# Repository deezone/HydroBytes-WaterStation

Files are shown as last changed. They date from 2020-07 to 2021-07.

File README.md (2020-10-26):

# HydroBytes-WaterManagement
A collection of systems using micro controllers to manage water in an automated garden.

## Introduction

The "garden" is simply a backyard patio in Brooklyn, New York. Typically there are only two seasons - cold and hot in New York City. By automating an urban garden ideally the space will thrive with minimum supervision. The amount of effort to automate is besides the point, everyone needs their vices.

- **Water Management**
- **[Base Station](https://github.com/deezone/HydroBytes-BaseStation)**

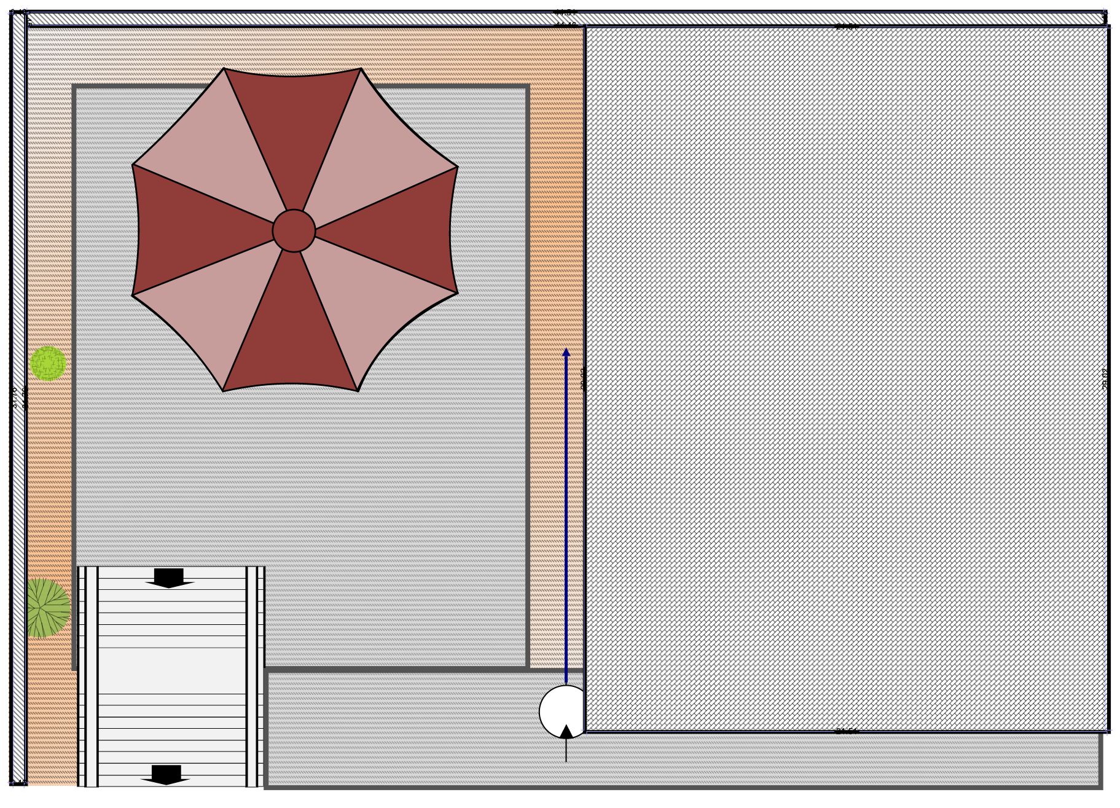
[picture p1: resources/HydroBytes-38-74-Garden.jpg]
Garden Layout


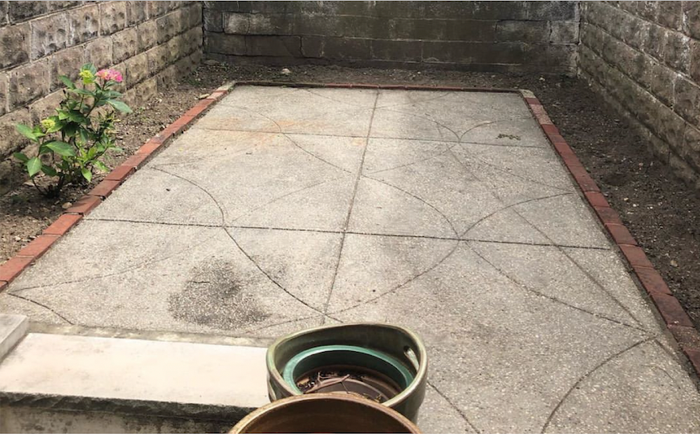
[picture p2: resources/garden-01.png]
Garden


### YouTube Channel

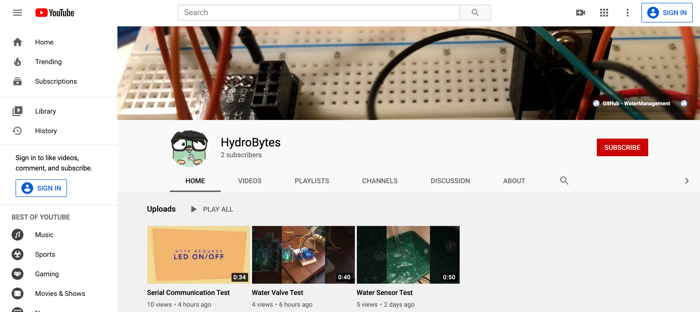
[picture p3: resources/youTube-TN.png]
YouTube Channel (https://www.youtube.com/channel/UC00A_lEJD2Hcy9bw6UuoUBA "All of the HydroBytes videos")


## The Water Management System

This repo is for the Water Management systems of the project. It's responsibilities are:
- adding water to a water reservoir (rain barrel)
- monitor the water level in the water reservoir
- pumping water to the garden. Sensor systems in the garden will coordinate with the Water Management system based on the conditions
- provide access and control of the subsystems through REST API requests
- send status and related readings to the Central System

### Release Notes
Resources and thoughts on each release. Development details as well as links to help explain choices made in how the system was built.

- [v0.2.1 - 24 October 2020](https://github.com/deezone/HydroBytes-waterManagement/blob/master/resources/releases/v00-02-01.md)
Adds duration  GET /water responses to indicate the amount of time since the water pump state has been toggled.
- [v0.2.0 - 18 October 2020](https://github.com/deezone/HydroBytes-waterManagement/blob/master/resources/releases/v00-02-00.md)
Water irrigation support. A request to irrigate the garden includes monitoring the current water level available.
- [v0.1.1 - 27 September 2020](https://github.com/deezone/HydroBytes-waterManagement/blob/master/resources/releases/v00-01-01.md)
Addition of YouTube channel as well as general release notes clean up to include images and videos to help document the project.
- [v0.1.0 - 30 August 2020](https://github.com/deezone/HydroBytes-waterManagement/blob/master/resources/releases/v00-01-00.md)
Water level detection on water barrel.
- [v0.0.3 - 15 August 2020](https://github.com/deezone/HydroBytes-waterManagement/blob/master/resources/releases/v00-00-03.md)
Working proof of concept. LED control and monitoring of state with http requests.
- [v0.0.2 - 14 August 2020](https://github.com/deezone/HydroBytes-waterManagement/blob/master/resources/releases/v00-00-02.md)
Adds functional two way serial communication between Ardunio Uno and ESP8266 ESP-01 as a part of a GET /status 200 response.
- [v0.0.1 - 25 July 2020](https://github.com/deezone/HydroBytes-waterManagement/blob/master/resources/releases/v00-00-01.md)
Functional solution to two controllers - Arduino Uno and ESP8266 ESP-01 communicating through a serial connection. The ESP provides a WiFi access point and the Uno works with all of the sensors.

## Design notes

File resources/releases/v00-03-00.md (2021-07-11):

# Release v0.4.0
16 June 2021

### Features

- Switch to the NodeESP (ESP-12f)

- Add DS3231 hardware for real time clock functionality
- Add clock values to irrigation duration calculations

### Bug Fixes

- 

### Refactors

- 

### Learnings

- 

**References**:

- [Library: DS3231](http://www.rinkydinkelectronics.com/library.php?id=73)
The DS3231 is a low-cost, extremely accurate I2C realtime clock (RTC) with an integrated temperature-compensated crystal oscillator (TCXO) and crystal. The device incorporates a battery input, and maintains accurate timekeeping when main power to the device is interrupted. The integration of the crystal resonator enhances the long-term accuracy of the device as well as reduces the piece-part count in a manufacturing line.
- [Installing Additional Arduino Libraries - Importing a .zip Library](https://www.arduino.cc/en/guide/libraries#toc4)
- [Arduino and DS3231 Real Time Clock Tutorial](https://howtomechatronics.com/tutorials/arduino/arduino-ds3231-real-time-clock-tutorial/)
Learn how to use the DS3231 Real Time Clock Module
- [8 tips to use the String class efficiently](https://cpp4arduino.com/2018/11/21/eight-tips-to-use-the-string-class-efficiently.html)
The String class provides a convenient means to bring a Flash string into the RAM temporarily. Avoiding heap allocation is not always possible. Many Arduino cores (most notably the ones for ESP8266 and ESP32) put a very low limit on the stack size, so it’s not possible to put large strings there. In this case, using the String class makes perfect sense. Some libraries (for example ESP8266WebServer) force the use the String class.

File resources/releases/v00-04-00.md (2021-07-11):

# Release v0.4.0
16 June 2021

### Features

- Switch to the NodeESP (ESP-12f)

- Add DS3231 hardware for real time clock functionality
- Add clock values to irrigation duration calculations

### Bug Fixes

- 

### Refactors

- 

### Learnings

- 

**References**:

- [Library: DS3231](http://www.rinkydinkelectronics.com/library.php?id=73)
The DS3231 is a low-cost, extremely accurate I2C realtime clock (RTC) with an integrated temperature-compensated crystal oscillator (TCXO) and crystal. The device incorporates a battery input, and maintains accurate timekeeping when main power to the device is interrupted. The integration of the crystal resonator enhances the long-term accuracy of the device as well as reduces the piece-part count in a manufacturing line.
- [Installing Additional Arduino Libraries - Importing a .zip Library](https://www.arduino.cc/en/guide/libraries#toc4)
- [Arduino and DS3231 Real Time Clock Tutorial](https://howtomechatronics.com/tutorials/arduino/arduino-ds3231-real-time-clock-tutorial/)
Learn how to use the DS3231 Real Time Clock Module
- [8 tips to use the String class efficiently](https://cpp4arduino.com/2018/11/21/eight-tips-to-use-the-string-class-efficiently.html)
The String class provides a convenient means to bring a Flash string into the RAM temporarily. Avoiding heap allocation is not always possible. Many Arduino cores (most notably the ones for ESP8266 and ESP32) put a very low limit on the stack size, so it’s not possible to put large strings there. In this case, using the String class makes perfect sense. Some libraries (for example ESP8266WebServer) force the use the String class.
- [Stack vs Heap: Know the Difference](https://www.guru99.com/stack-vs-heap.html)
  KEY DIFFERENCES
  - Stack is a linear data structure whereas Heap is a hierarchical data structure.
  - Stack memory will never become fragmented whereas Heap memory can become fragmented as blocks of memory are first allocated and then freed.
  - Stack accesses local variables only while Heap allows you to access variables globally.
  - Stack variables can’t be resized whereas Heap variables can be resized.
  - Stack memory is allocated in a contiguous block whereas Heap memory is allocated in any random order.
  - Stack doesn’t require to de-allocate variables whereas in Heap de-allocation is needed.
  - Stack allocation and deallocation are done by compiler instructions whereas Heap allocation and deallocation is done by the programmer.
- [What is Heap Fragmentation?](https://cpp4arduino.com/2018/11/06/what-is-heap-fragmentation.html)
The “heap” is the area of the RAM where the dynamic memory allocation happens.
YouTube Channel (https://cpp4arduino.com/2018/11/06/what-is-heap-fragmentation.html "[What is Heap Fragmentation?")

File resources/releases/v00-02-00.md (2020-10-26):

# Release v0.2.0
18 October 2020

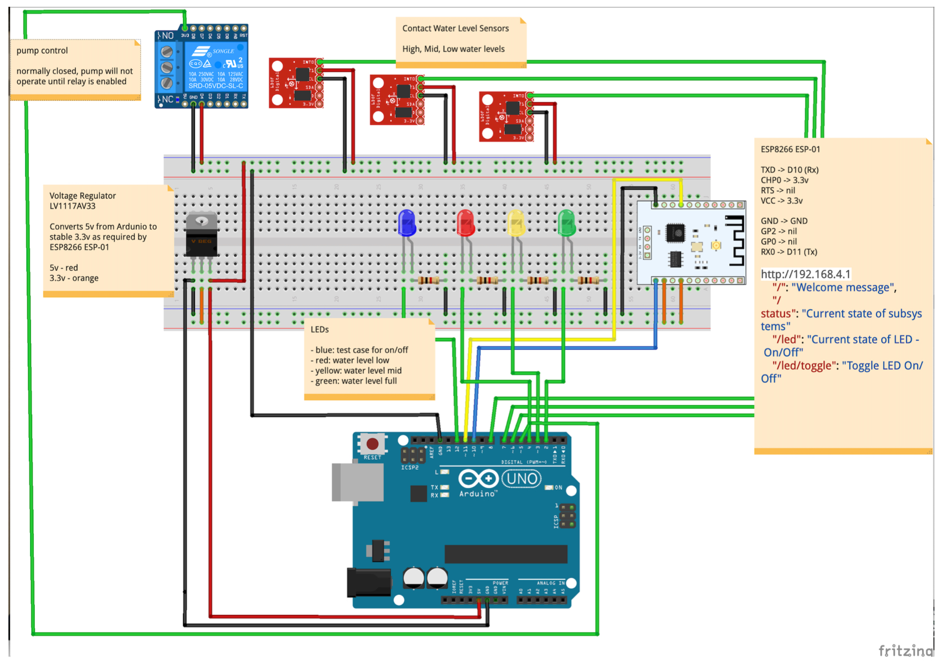
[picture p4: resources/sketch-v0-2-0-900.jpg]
v0-2-0-schematic


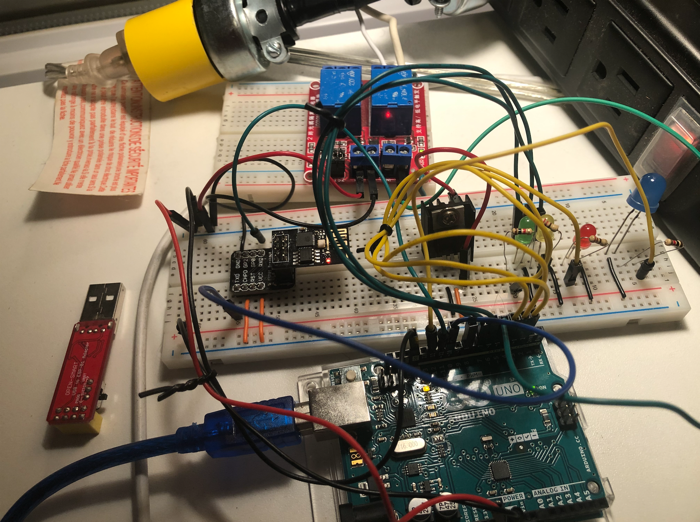
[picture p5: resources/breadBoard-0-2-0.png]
v0-2-0-breadboard


@todo Release video

Release and installation of water irrigation functionality.

Requests to:
```
GET http://192.168.4.1/water
```
returns a status response based on:
- the current status of the water pump
- the water level detected
- the amount of time (in seconds) since the state of the pump has changed
```
{
  water: {
    level: empty | low | mid | full
    irrigation: {
      status: on | off
      duration: 000 (seconds)
    }
  }
}
```

```
GET http://192.168.4.1/water/irrigate?duration=xx&safety=disabled
```
returns the toggled state of the water pump. Parameter support for:
```
duration=xx (optional)
safety=disabled (optional)
```
- `duration`: the amount of time (in seconds) to irrigate
- `safety`: manage the safety check of the water level when irrigating to ensure there is water is available when the water pump is running

### Water Level LEDs
Fixed bug where each LED for each of the possible water levels was not turning on/off based on the related water level sensor reading.

@todo picture of working leds

### Pump Control with Relay
In order to control the on/off state of the water pump of ??v using a 5v digital pin on the Arduino Uno, a relay is used. The relay is a magnetic switch that can be turned on or off with low voltage but manages the flow of a much higher voltage. The relay provides isolation to prodect the low voltage controllers when managing much higher voltage devices such as the water pump.

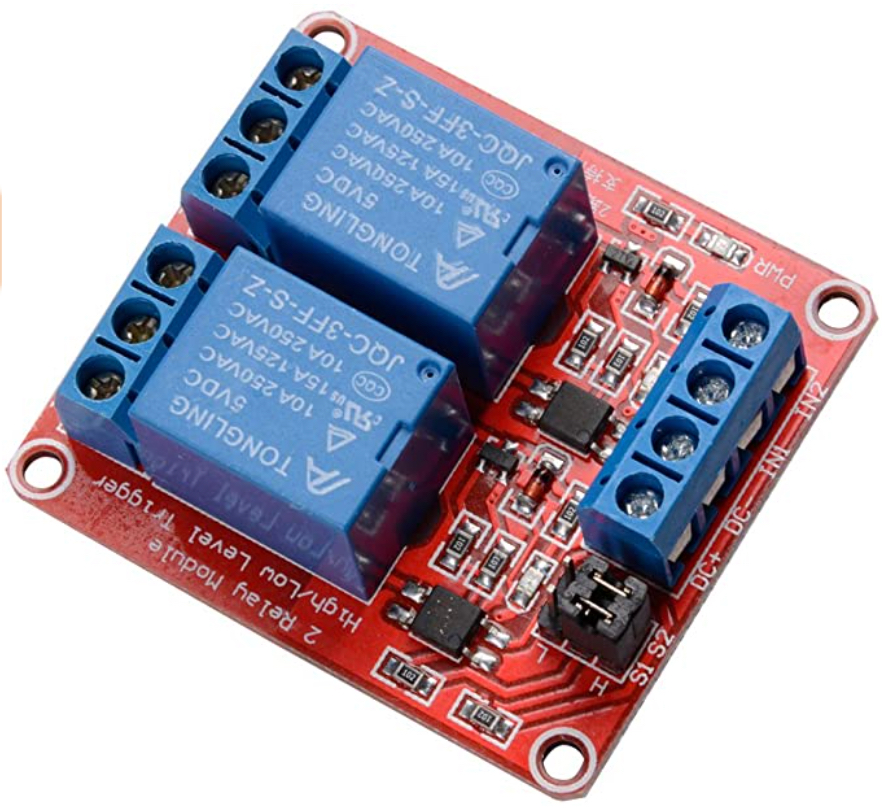
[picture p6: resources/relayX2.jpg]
relay


### Installation
Added dupont connectors to sensor lines to allow for easy disconnect from the breadboard. This allows the breadboard to be moved for upgrades.

@todo picture of dupont connector

### Learnings

On the Ardino board, some of the digital pins are labelled with the ~ character which indicates "Pulse Width Modulation" ([Arduino PWM Tutorial](https://create.arduino.cc/projecthub/muhammad-aqib/arduino-pwm-tutorial-ae9d71)). Digital pins are binary, on or off, 0 or 1. PWM adds the ability to simulate an anologue pin that can have a range of values (volatages) by turning the pin on and off with gaps. In effect, a range of values can be generated for use with to things like LED brightness.

**References**:

- [REST server on esp8266 and esp32: GET and JSON formatter – Part 2](https://www.mischianti.org/2020/05/24/rest-server-on-esp8266-and-esp32-get-and-json-formatter-part-2/)
Example of how to use ArduinoJson library to create json response bodies.
- [ArduinoJson Assistant](https://arduinojson.org/v6/assistant)
A tool to determine the JsonDocument size.

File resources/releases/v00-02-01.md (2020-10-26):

# Release v0.2.1
24 October 2020

v0-2-0-breadboard

Enhance water irrigation functionality with water level check.

Requests to:
```
GET http://192.168.4.1/water
```
and
```
GET http://192.168.4.1/water/irrigate
```
returns a status response based on:
- the current status of the water pump
- the water level detected
- the amount of time since the state of the pump has changed
```
{
  water: {
    level: empty | low | mid | full
    irrigation: {
      status: on | off
      duration: 000 (hh:mm:ss)
    }
  }
}
```

### Water Level LEDs
Fixed bug where each LED for each of the possible water levels was not turning on/off based on the related water level sensor reading.

### Pump Control with Relay
In order to control the on/off state of the water pump of 24v using a 5v digital pin on the Arduino Uno, a relay is used. The relay is a magnetic switch that can be turned on or off with low voltage but manages the flow of a much higher voltage. The relay provides isolation to protect the low voltage controllers when managing much higher voltage devices such as the water pump.

### Installation
Added dupont connectors to sensor lines to allow for easy disconnect from the breadboard. This allows the breadboard to be moved for upgrades.

@todo picture of dupont connector installation

### Learnings

On the Arduino board, some of the digital pins are labelled with "~" which indicates **"Pulse Width Modulation"** ([Arduino PWM Tutorial](https://create.arduino.cc/projecthub/muhammad-aqib/arduino-pwm-tutorial-ae9d71)). Digital pins are binary, on or off, 0 or 1. PWM add the ability to simulate an analogue pin that can have a range of values (voltages) by turning the pin on and off with gaps. In effective a range of values can be applied to things like LED brightness.

More research needs to be done on the use of the **`String` variable type**. There appears to be a significant concern that it's use with microcontrollers should be avoided. Due to how it uses and manages memory performance and potential bugs are a concern. Initial efforts to move to a clearly defined buffer using the `char` variable type was used for the `irrigation_duration` response:
```
  char localbuf[9];
  sprintf(localbuf, "%02d:%02d:%02d", hours, minutes, seconds);
  Serial.println(localbuf);
```

Future versions that need event based functionality could use "Internal Timers". For example[the passing of a certain amount of time or when a pin changes state a certain amount of times could be a trigger. See [Internal Timers of Arduino](https://create.arduino.cc/projecthub/Marcazzan_M/internal-timers-of-arduino-58f6c9).

**References**:

- [REST server on esp8266 and esp32: GET and JSON formatter – Part 2](https://www.mischianti.org/2020/05/24/rest-server-on-esp8266-and-esp32-get-and-json-formatter-part-2/)
Example of how to use ArduinoJson library to create json response bodies.
- [ArduinoJson Assistant](https://arduinojson.org/v6/assistant)
A tool to determine the JsonDocument size.

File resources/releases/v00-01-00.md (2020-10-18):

# Release v0.1.0
30 August 2020

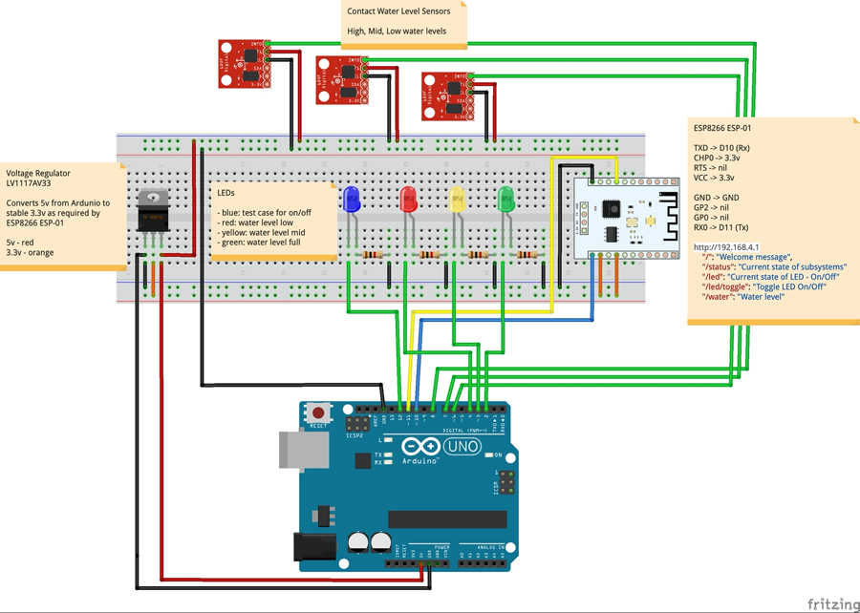
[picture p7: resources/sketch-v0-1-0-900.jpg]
v0-1-0-schematic


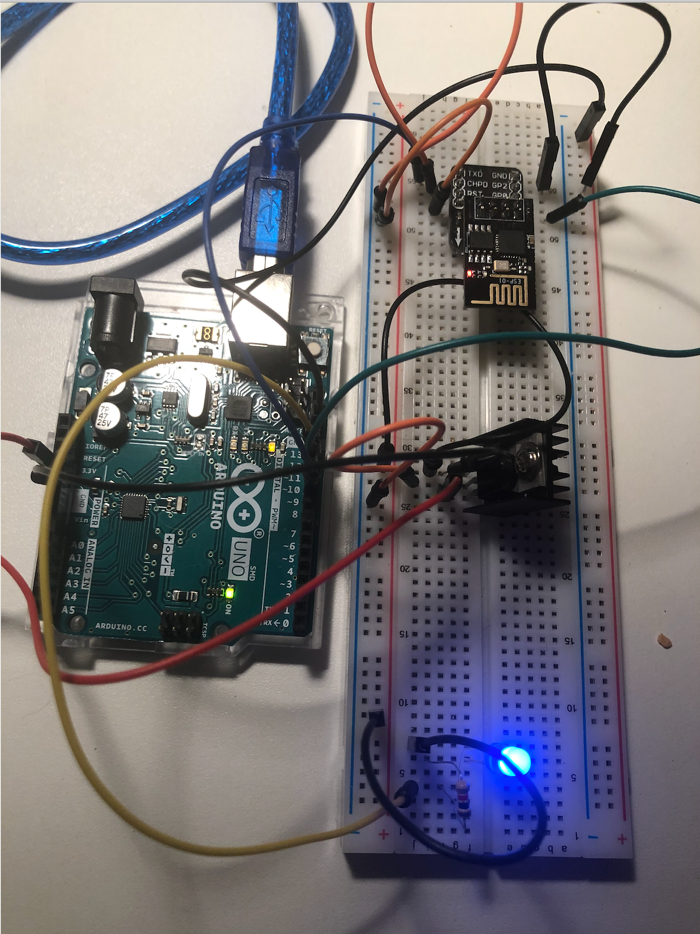
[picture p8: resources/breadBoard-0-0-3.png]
v0-1-0-breadboard


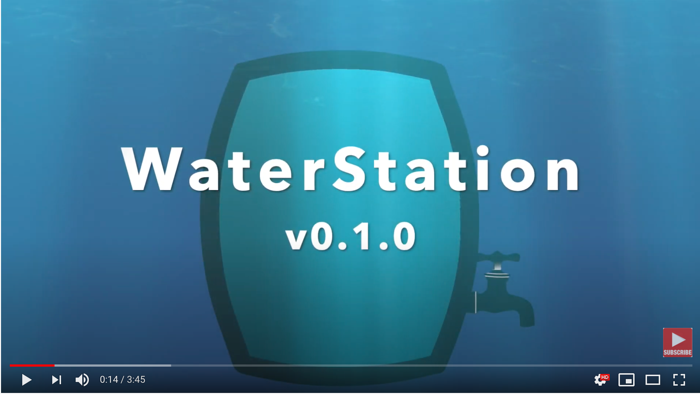
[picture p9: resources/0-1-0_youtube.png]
YouTube Channel (https://youtu.be/to24BdlBJDs "0.1.x release summary")


Release and installation of water level sensors on water barrel. Requests to:
```
GET http://192.168.4.1/water
```
return a response based on the water level detected:
```
{
  water: {
    level: empty | low | mid | full
  }
}
```

### Sensor

Three water sensors determine the water level in the water barrel. The sensors make digital readings (1 or 0) based on the detection or water. A reading at the three levels: low, mid or high as well as empty determines the current water level.

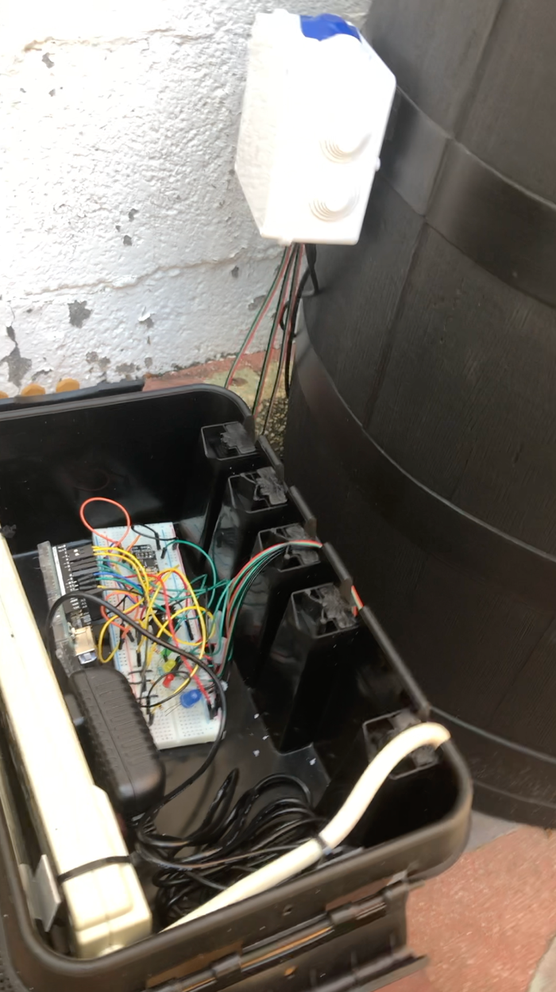
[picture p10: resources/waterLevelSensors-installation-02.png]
v0-1-0-waterSensor-installation-02


#### CQRobot Contact Water/Liquid Level Sensor

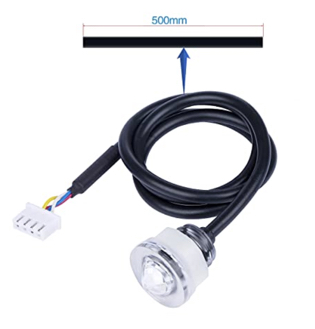
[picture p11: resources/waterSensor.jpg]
CQRobot Contact Water/Liquid Level Sensor


- Low Power Consumption
- Corrosion Resistance
- High Pressure Resistance
- High Temperature Resistance

An interface board that can be toggled between 3.3/5v converts the sensor reading to a digital signal.

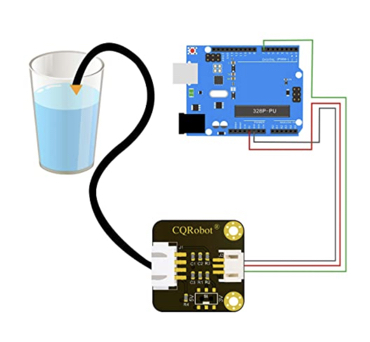
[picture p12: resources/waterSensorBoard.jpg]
CQRobot Contact Water/Liquid Level Board


### Installation

Installation of the sensors involved drilling holes in the water barrel based on the diameter of the CQRobot Contact water sensors. Due to the length of the sensor wires a water proof junction box was used to house the digital interface cards for each of the sensors.

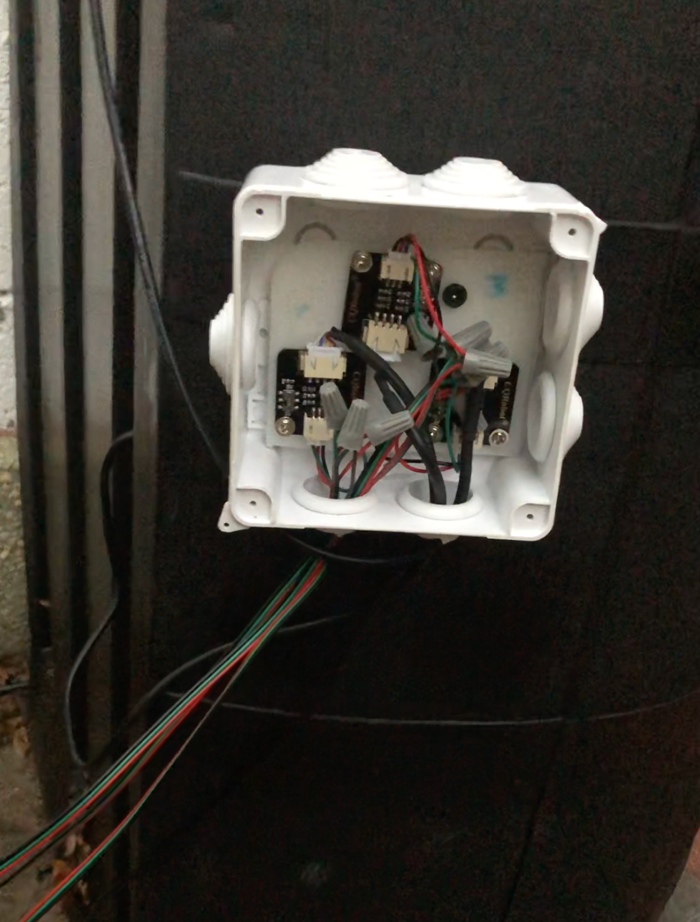
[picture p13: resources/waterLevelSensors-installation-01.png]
v0-1-0-waterSensor-installation-01


Three LEDs were added to the breadboard for each of the possible water level readings. The LEDs will be used for debugging and removed with the next release.

### Learnings

Wire gauge (thickness) is important factor when considering the distance / length of the wire relative to the current and voltage that needs to be applied. In this case the gauge used was typical of Arduino projects but more research is needed to determine if a different gauge should be used. This should take into consideration the robustness needed for a long term outdoor environment.

**References**:

- [Liquid Level Sensor](http://www.cqrobot.wiki/index.php/Liquid_Level_Sensor)
CQRobot Contact Water/Liquid Level Sensor, This is a photoelectric water liquid level sensor that is operates using optical principles.
- [LIQUID FLOW METER - PLASTIC 1/2" NPS THREADED](https://www.adafruit.com/product/828)
- [Using Unit Test Frameworks With Arduino](https://maker.pro/arduino/tutorial/using-unit-test-frameworks-with-arduino)
Learn different ways to unit test your Arduino code with these methods and frameworks.
- [bxparks/AUnit](https://github.com/bxparks/AUnit)
A unit testing framework for Arduino platforms inspired by by ArduinoUnit and Google Test. The unit tests usually run on the embedded controller which allows detection of architecture-specific problems.
- [Matching Wire Size to Circuit Amperage](https://www.thespruce.com/matching-wire-size-to-circuit-amperage-1152865#:~:text=Wire%20is%20sized%20by%20the,the%20larger%20the%20wire%20diameter.)
Whenever a circuit is extended or rewired, or when any new circuit is installed, it is critical that the new wiring is made with wire conductors that are properly sized for the amperage rating of the circuit.

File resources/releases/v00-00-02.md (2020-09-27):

# Release v0.0.2

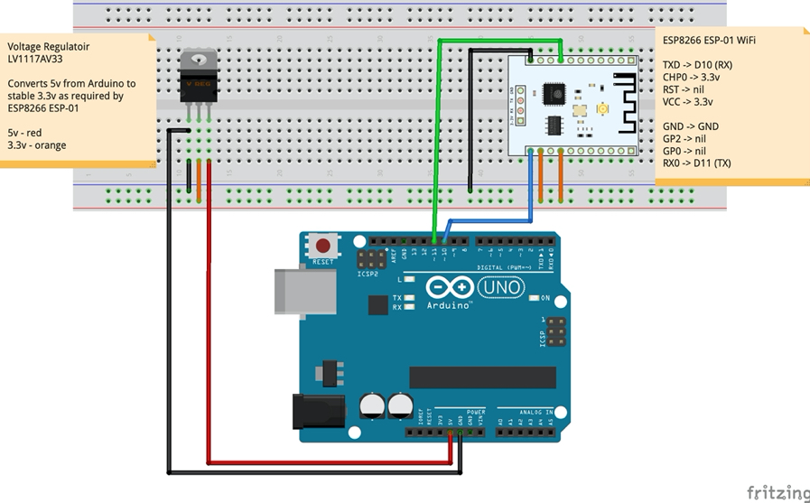
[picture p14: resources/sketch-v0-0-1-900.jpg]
HydroBytes v0-0-2-schematic


### Two way serial communication - Arduino Uno to ESP8266 ESP-01

This release adds important functionality on how to implement two way serial communication. A request to GET /status includes confirmation that a two way serial connection exists and is working. The response to the request has a specific confirmation:

```
200
{
  status: {
    "two-way-serial-communication": "true"
  }
}
```

or in the case of an error:
```
503
{
  status: {
    "two-way-serial-communication": "false"
  }
}
```

### Root request updated

The root request; GET / has been updated to make room for a response that includes general information about the site.

```
GET /
{
  "hydrobytes-water-station": "ok",
  "paths": {
    "/": "Welcome message",
    "/status": "Current state of subsystems"
  }
}
```

### Debugging
An important discovery of how to debug the the ESP-01 is to use the [USB to ESP8266 Adaptor Module](https://www.amazon.com/Wireless-ESP8266-Adapter-ESP-01S-Transceiver/dp/B07NWD1TQM) to toggle between PROG and UART mode using the switch on the board. After writing the updated code use UART mode and the serial terminal in the Arduino IDE to mimic serial communication.

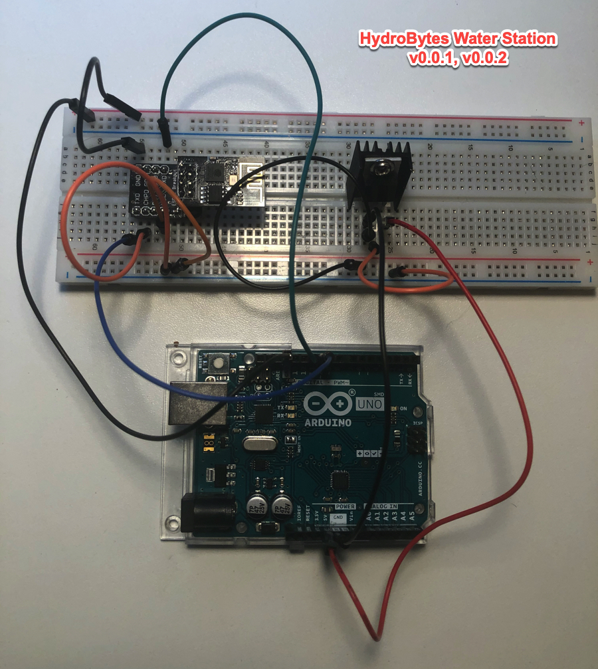
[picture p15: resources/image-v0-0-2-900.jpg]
HydroBytes v0-0-2-image


### Resources
- [Arduino Tutorial: Serial Inputs](https://www.norwegiancreations.com/2017/12/arduino-tutorial-serial-inputs)
An guide to possible applications for Serial input/output. This can be for debugging as well as communication between devices.

**Serial.available()** returns the number of characters (i.e. bytes of data) which have arrived in the serial buffer and that are ready to be read.

**Serial.read()** returns the first (oldest) character in the buffer and removes that byte of data from the buffer. So when all the bytes of data are read and no new serial data have arrived, the buffer is empty and Serial.available() will return 0.

**readStringUntil()** function, which makes it possible to combine all the characters in the sent message into a single Arduino string. In the case of `command = Serial.readStringUntil('\n');` the `\n` character, which is the newline character that comes at the end of a string sent in the Arduino serial monitor or with `Serial.println("TEST");`.

- [Serial Communication - Arduino UNO and ESP8266 (ESP-01)](https://www.youtube.com/watch?v=ji71cHaGW8wz0)
A video example of serial communication between ESP-01 and Uno. Includes basic hardware debugging.

- [Tutorial 06 for Arduino: Serial Communication and Processing](https://www.youtube.com/watch?v=g0pSfyXOXj8)

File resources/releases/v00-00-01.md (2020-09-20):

# Release v0.0.1
25 July 2020

HydroBytes v0-0-2-schematic

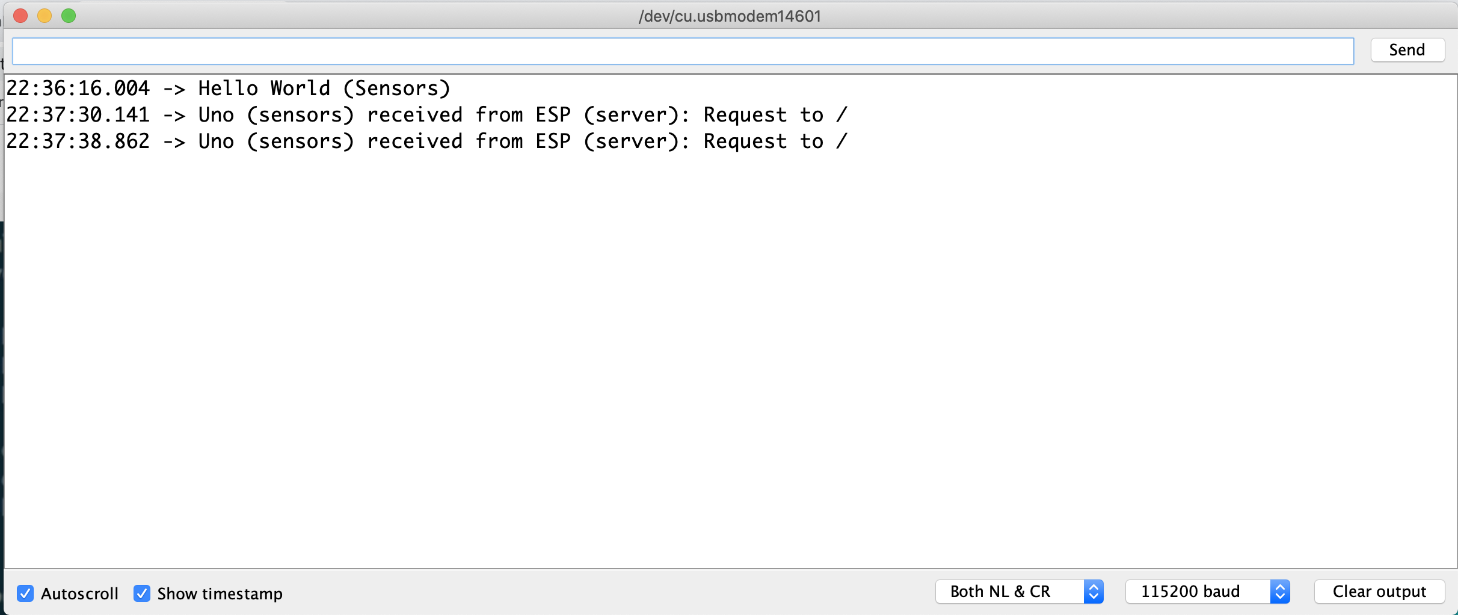
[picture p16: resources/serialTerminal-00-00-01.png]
SerialTerminal


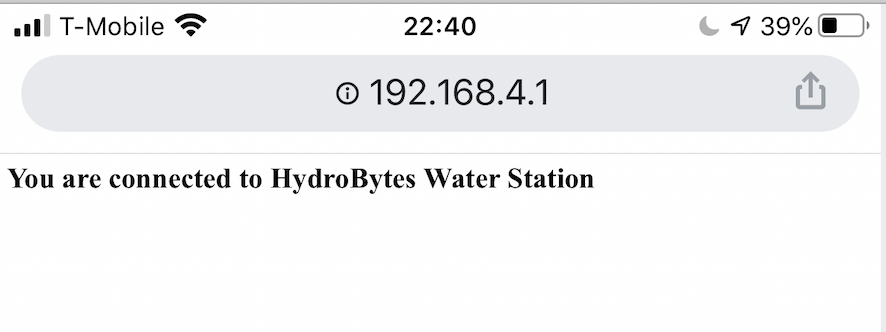
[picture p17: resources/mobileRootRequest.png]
MobileClientRootRequest


### WiFi - Arduino Uno serial to esp8266

This release was a significant break through for wireless connectivity for the station.

In searching for a solution, it was discovered that there are many ways to approach adding WiFi to an Arduino micro controller. The most common is to access the WiFi functionality on an esp8266. It is often confused with the assumption that the esp8266 is an add on to the Arduino much like a sensor. The two are actually fully functional separate controllers. 

The esp8266, has WiFi built in but also has a fully functional programmable controller as well as pin in/outs. There are many models of the esp8266, this release uses the most basic and the original esp-01.

The solutions often use AT commands sent serially from the Ardunio to the esp8266 with it's default firmware. The AT commands setup and manage WiFi communication. This proved to be a fragile arrangement as it depends on the serial communication being reliable. RS-232 communication should always have logic to deal with errors.

A more robust solution, used by this project is to flash the ESP8266 with the Arduino library and use the dedicated packages:
```
#include <ESP8266WiFi.h>
#include <WiFiClient.h>
#include <ESP8266WebServer.h>
```
which adds all of the AT functionality.

### Consistent Power (LD1117AV33)

Also a significant discovery, as a part of this release, is the need for a stable 3.3v source for the ESP8266. The 3.3v power pin on the Arduino Uno does not always provide sufficient voltage. Depending on what else the board is doing the level can drop. This causes the ESP8266 to not function properly and typically restart.

The solution was the use of a 3.3 voltage regulator ([3.3v LDO LD1117AV33](https://www.adafruit.com/product/2165)). Using the Arduino Uno 5v source, the regulator converts the voltage to a stable 3.3v level.

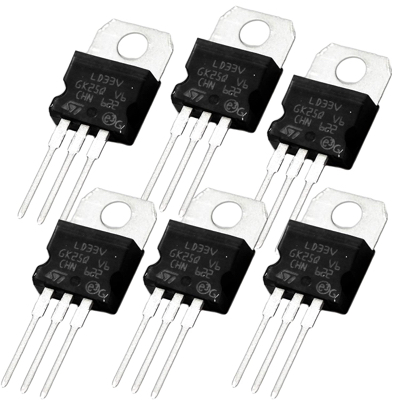
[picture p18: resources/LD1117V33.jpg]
LD1117V33


### Flashing the ESP8266-ESP-01

Often the Uno in Reset mode is used to pass through to flash the esp8266. An easier and more reliable method is to use a [USB to ESP8266 Adaptor Module](https://www.amazon.com/Wireless-ESP8266-Adapter-ESP-01S-Transceiver/dp/B07NWD1TQM). Note the switch that allows reading and writing to the ESP-01. The switch removes the need to solder pins. Both functions can be performed using the same setup.

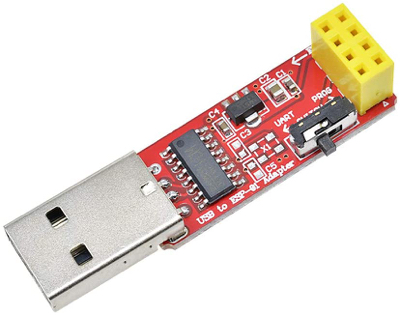
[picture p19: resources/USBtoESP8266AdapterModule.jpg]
USB to ESP8266 Adaptor Module


### Resources
- [ESP8266 Web Server Step-By-Step Using Arduino IDE (Mac OSX and Windows)](https://www.youtube.com/watch?v=m2fEXhl70OY)
An important first step in the project that explains how to use an esp8266 as a web server.
- [Serial Communication - Arduino UNO and ESP8266 (ESP-01)](https://www.youtube.com/watch?v=ji71cHaGW8w)
- [Serial Communication - ESP-01 to Arduino](https://www.youtube.com/watch?v=iRmfnfAZRe4)
The other part of the important first step in this project that shows how to setup serial communication between an Arduino Uno and an ESP8266 ESP-01 in both directions.

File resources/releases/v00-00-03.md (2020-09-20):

# Release v0.0.3
15 August 2020

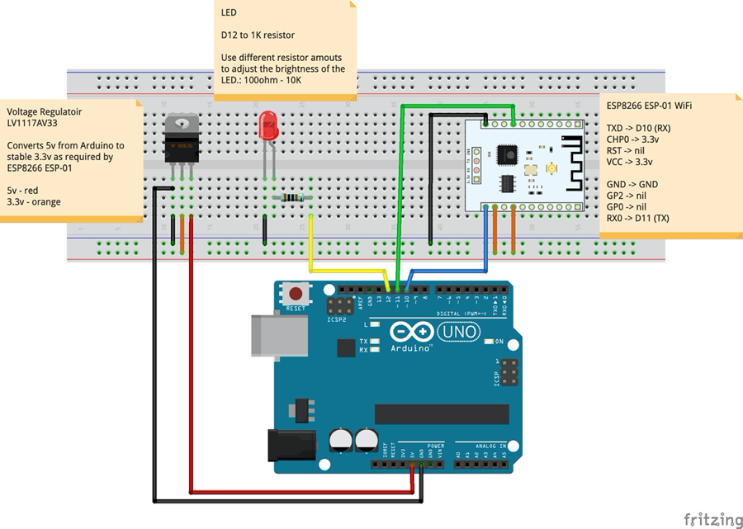
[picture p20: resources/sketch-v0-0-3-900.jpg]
v0-0-3-schematic


 A working solution of http requests controlling and monitoring a LED. Proof of concept ("SPIKE") for sending requests to trigger a watering event.

When connected to the access point "HydroBites-WaterStation"

```
GET http://192.168.4.1
```
Responds with information about the server:
```
200
{
  "hydrobytes-water-station": "ok"
  "paths": {
    "/": "Welcome message",
    "/status": "Current state of subsystems"
    "/led": "Current state of LED - On/Off"
    "/led/toggle": "Toggle LED On/Off"
  }
}
```

```
GET http://192.168.4.1/led
```
Checks the status of the LED.
```
200
{
  status: {
    led-on: false
  }
}
```

```
GET http://192.168.4.1/led/toggle
```
Toggles the LED on and off.
```
{
  status: {
    led-on: true
  }
}
```

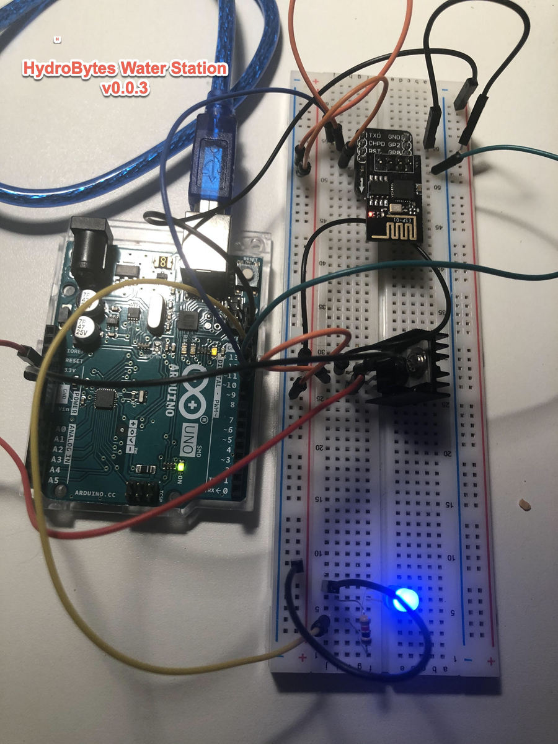
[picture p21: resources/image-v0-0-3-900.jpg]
v0-0-3-image


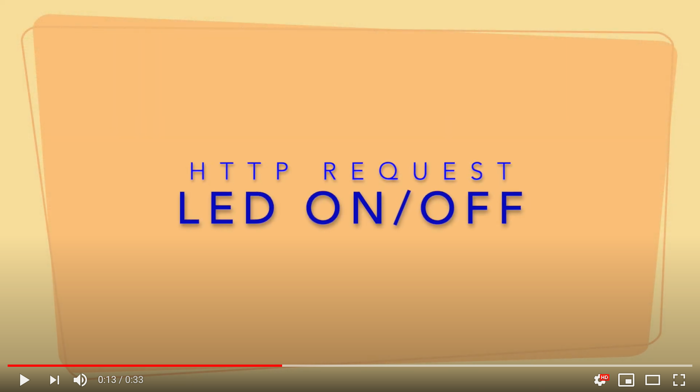
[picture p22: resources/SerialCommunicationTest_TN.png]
Serial Communication Test (https://www.youtube.com/watch?v=tVkIvw4ubZU "Serial communication to control LED")


**References**:
- [ESP8266 First Web Server](https://tttapa.github.io/ESP8266/Chap10%20-%20Simple%20Web%20Server.html)
- [acrobotic/Ai_Tips_ESP8266 - simple webserver](https://github.com/acrobotic/Ai_Tips_ESP8266/blob/master/simple_webserver/simple_webserver.ino)
- [Basic LED setup for beginners](https://create.arduino.cc/projecthub/karmette/basic-led-setup-for-beginners-0a124a)

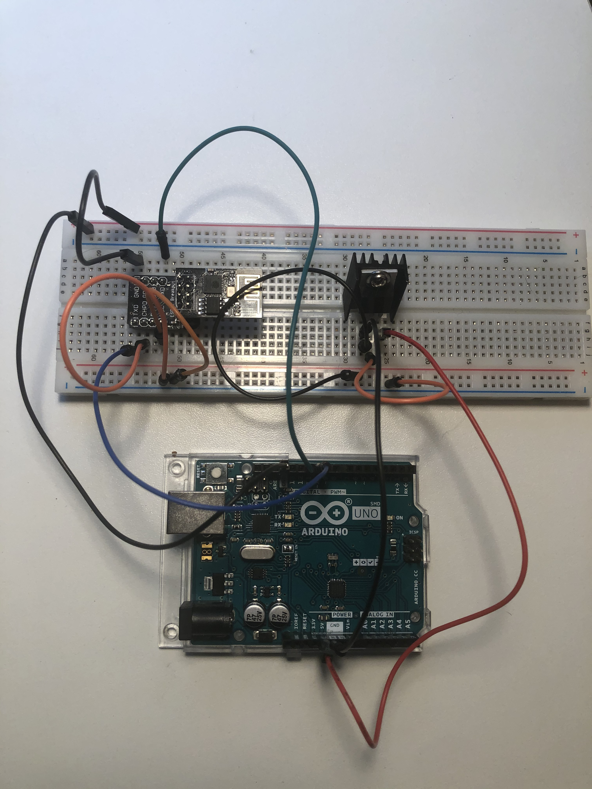
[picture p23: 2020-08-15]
resources/image-v0-0-1-900.jpg

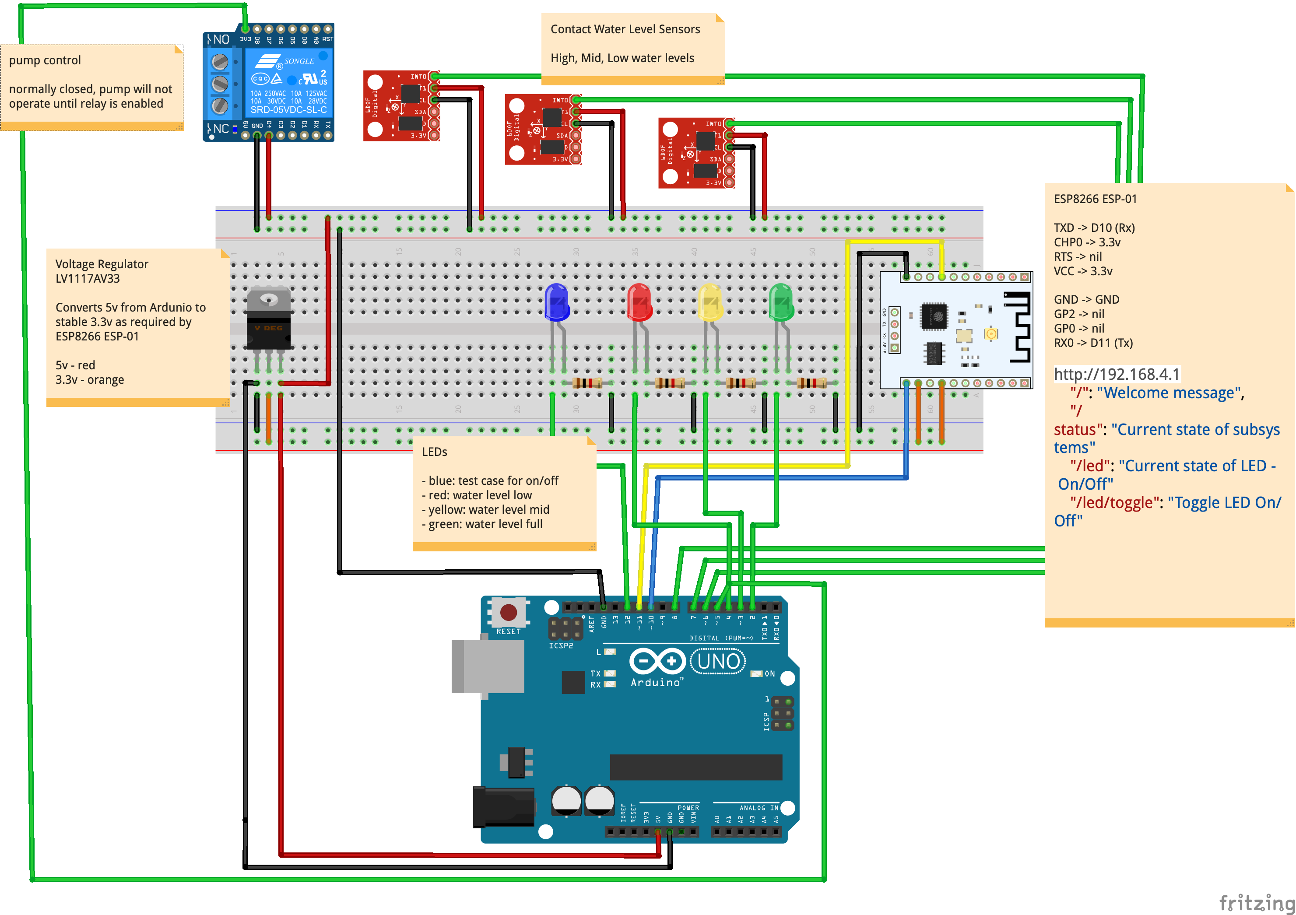
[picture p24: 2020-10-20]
resources/sketch-v0-2-x.png

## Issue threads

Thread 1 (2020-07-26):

[SPIKE] LED control through http request

deezone, 2020-07-26:
Work through how to control turning a LED on and off with REST requests:

**Turn LED on and off**:
- GET http://192.168.4.1/led/toggle

Should turn on the test LED and respond with:
```
200
{
  led_enabled: true || false
}
```

**Turn LED off**:
- GET http://192.168.4.1/led/state

Gets the current state of the LED:
```
200
{
  led_enabled: true || false
}
```

### Note:

This is preliminary work to support station functionality:

- **start watering cycle**:
```
GET http://192.168.4.1/triggerWaterCycle?duration=100 (seconds)

200
{
  waterCycle: {
      running: true,
      utc_start_time: "Sun Jan  9 03:07:41 2011"
    }
}
```
Checks water level, fills water barrel and turns on water pump for time period

- **check water level**
```
GET http://192.168.4.1/waterLevel

200
{
  water: 0 || 1 || 2 || 3
}
```

Closed 2020-08-16.

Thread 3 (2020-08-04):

Impliment water level sensors

deezone, 2020-08-04:
Based on experiment `waterLevel1`, impliment water sensors:

- install CQRobat digital boards in water proof breakout box
- install sensors into rain barrel
- use test logic:

```
// initialize pins
int waterSensorHighPin = 6;
int waterSensorLowPin = 7;

int waterSensorHighStatus;
int waterSensorLowStatus;

void setup() {
  Serial.begin(9600);

  pinMode(waterSensorHighPin, INPUT);
  pinMode(waterSensorLowPin, INPUT);
}

void loop() {
  waterSensorLowStatus = digitalRead(waterSensorLowPin);
  waterSensorHighStatus = digitalRead(waterSensorHighPin);

  Serial.println(waterSensorLowStatus);
  Serial.println(waterSensorHighStatus);

  delay(100);
}
```

### Possible endpoints:

- **start watering cycle**:
```
GET http://192.168.4.1/triggerWaterCycle?duration=100 (seconds)

200
{
  waterCycle: {
      running: true,
      utc_start_time: "Sun Jan  9 03:07:41 2011"
    }
}
```
Checks water level, fills water barrel and turns on water pump for time period

- **check water level**
```
GET http://192.168.4.1/waterLevel

200
{
  water: 0 || 1 || 2 || 3
}
```

Closed 2020-09-03.

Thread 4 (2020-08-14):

[SPIKE] Two way serial communication

deezone, 2020-08-14:
Create working demonstration of two serial communication between sensor microcontroller (Arduino Uno) and server (ESP-8266 ESP-01).

Log serial messages to sensor Serial to allow for Arduino IDE serial monitor to display messages from both devices. Log messages should look something like:

```
23:56:18.707 -> sensor - from server: server received: Sensor PONG
23:56:18.780 -> sensor - from server: server -> PING
```

Closed 2020-08-15.

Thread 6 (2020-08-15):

[SPIKE] Serial -> NeoSWSerial

deezone, 2020-08-15:
Investigate switching from Ardunio Serial library to [SlashDevin / NeoSWSerial](https://github.com/SlashDevin/NeoSWSerial).

>  SoftwareSerial is so inefficient that it almost certainly interferes with other parts of your sketch.  And it cannot transmit and receive at the same time.  It wastes the CPU time every time it sends or receives one character, making the Arduino twiddle its thumbs for 1ms at 9600 baud.  It could have executed 10,000 instructions during that time.

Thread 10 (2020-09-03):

Implement water pump

deezone, 2020-09-03:
Based on experiments controlling a relay, add logic to turn a water pump on and off. Added logic should include:
- [ ] GET /water/pump : responds with status (pumping/idle) of pump including check of water level to include estimate of run time to low/empty
- [ ] GET /water/pump/toggle : toggles water pump on and off, includes safety check of water level as water is pumped
- [ ] LED on breadboard for debugging that toggles with water pump state

**Research Source**:
```
const int RELAY_ENABLED = 2;

void setup() {
  pinMode(RELAY_ENABLED, OUTPUT);
  pinMode(LED_BUILTIN, OUTPUT);

  Serial.begin(9600);
}

void loop() {
  Serial.println("Relay ON");
  digitalWrite(LED_BUILTIN, LOW);
  digitalWrite(RELAY_ENABLED, LOW); // The relay is active low, it turns on when set to LOW
  delay(1000);

  Serial.println("Relay OFF");
  digitalWrite(LED_BUILTIN, HIGH);
  digitalWrite(RELAY_ENABLED, HIGH);
  delay(1000);
}
```

**NOTE**:
- runtime of the pump is determined by the volume of the water barrel and the rate the pump drains the water. This could be future work once first full release of system has all functioning subsystems
- `v0.2.0`

Closed 2020-10-20.

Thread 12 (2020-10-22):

v0.2.1 - water pump / irrigation++

deezone, 2020-10-22:
Further enhancements for water pump / irrigation functionality:

- convert server responses to use `ArduinoJson` library rather that custom strings
- covert serial communication between sensor and server controllers to use short form messages. Ex:
```
ss: 1 - sensor_status: true
ir: 1 - irrigation_status: on
```
- add water level and irrigation duration to `GET /water/irrigate` response
- add Dupont Connectors to water sensor breadboard connections to support easy disconnect for controller updates off site
- complete pump and water line installation
- update `v0.2.0` release notes
- add `v0.2.1` release notes and supporting media

Closed 2020-10-29.

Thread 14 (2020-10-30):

Implement Water Valve - v0.3.x

deezone, 2020-10-30:
Add support for water valve to add water to the water barrel via a water line.

In the case where a request to `GET /water/irrigate` results in the detection that the current water level of the barrel is too low to complete an irrigation cycle there is a need to fill the water barrel to a higher water level. When rain has not produced enough water to fill the barrel a water line can be used to supply additional water.

Using a solenoid valve, water from a water line will be controlled to add water to the barrel to a level determined by the water level sensors. The request to fill the barrel will be:

**Request:**
```
GET /water/replenish
```

**Response:**
```
{
    "water": {
        "level": "empty",
        "irrigation": {
            "status": "ok",
            "enabled": "off",
            "duration": "00:15:09"
        },
        "replenish": {
            "status": "ok"
            "enabled": "off",
        }
    }
}
```

**Test**
https://youtu.be/Cny6-fKEiL4

**Sample Code**
```
const int RELAY_ENABLED = 2;

void setup() {
  pinMode(RELAY_ENABLED, OUTPUT);
  pinMode(LED_BUILTIN, OUTPUT);

  Serial.begin(9600);
}

void loop() {
  Serial.println("Relay ON");
  digitalWrite(LED_BUILTIN, LOW);
  digitalWrite(RELAY_ENABLED, LOW); // The relay is active low, it turns on when set to LOW
  delay(1000);

  Serial.println("Relay OFF");
  digitalWrite(LED_BUILTIN, HIGH);
  digitalWrite(RELAY_ENABLED, HIGH);
  delay(1000);
}
```

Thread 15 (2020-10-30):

Make Station Network Subscriber

deezone, 2020-10-30:
Currently the Water Station uses an ESP8266 to provide WiFi  connectivity as an Access Point (AP) on a private wireless network. Once a Base Station is created it will be the AP for the HydroBytes Automated Garden system. The Water Management system needs to become a Station (STA) that connects to the AP.

- [ ] convert the Water Station ESP8266 to be a Station (STA)
- [ ] store access credentials in flash memory
- [ ] set ESP8266 to auto connect to the HydroBytes wireless network  automatically

**Resources:**

- **[HOW TO USE ESP8266 WIFI MODES: STATION AND ACCESS POINT](http://onlineshouter.com/use-esp8266-wifi-modes-station-access-point/)**
> SP8266 works in two modes: Station (STA) and Access Point (AP).  In short, AP mode allows it to create its own network and have other devices (your phone) connect to it and STA mode allows the ESP8266 to connect to a Wi-Fi network (one created by your wireless router)

- **[TUTORIAL:STORING WIFI CONFIGURATION ON YOUR ESP8266 USING THE EEPROM LIBRARY MADE SIMPLE](https://thekurks.net/blog/2017/11/6/esp8266-iot-eeprom-example)**
> The main reason is that the standard EEPROM library does not work, because the ESP8266 does not have an EEPROM. The library we use simply emulates an EEPROM but in real life we are writing to the FLASH Memory.

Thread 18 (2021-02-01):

Add trace context

deezone, 2021-02-01:
Based on details out in the video below add trace ids to the header of requests. Trace context will allow tracking the request life cycle across services.

Ardan Labs - Ultimate Service Version 1
Getting Production Ready - Distributed Tracing
https://education.ardanlabs.com/courses/take/ultimate-service-ver-1/lessons/7976153-19-2-distributed-tracing

Related PR: https://github.com/deezone/HydroBytes-BaseStation/issues/65

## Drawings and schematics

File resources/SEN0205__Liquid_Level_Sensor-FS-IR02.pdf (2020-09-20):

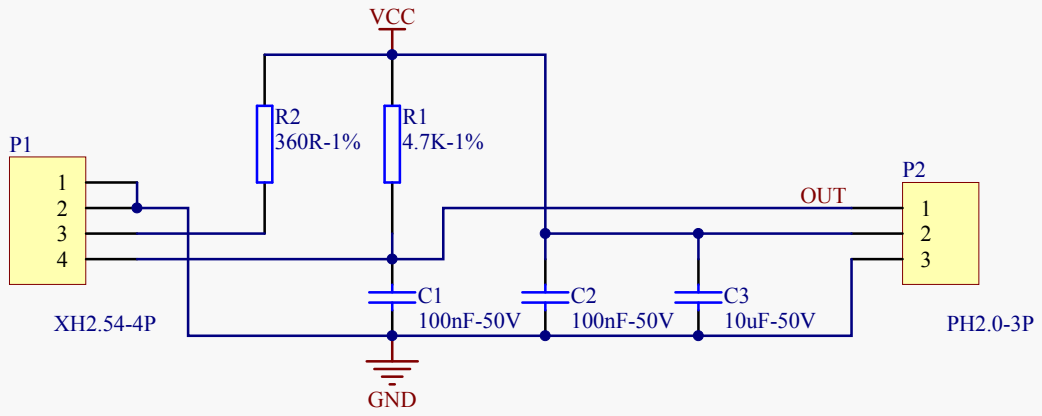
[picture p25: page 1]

Drawn: 1 of 1 jackli-CD | Revision: V1.0 | SKU: SEN0205 A4 Page: Size :
Title: Liquid Level Sensor-FS-IR02

Date : 2016/1/30 | Time: 16:16:40

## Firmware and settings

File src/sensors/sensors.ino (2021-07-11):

/**
 * HydroBites WaterStation sensors
 * 
 * DS3231
 * https://github.com/Makuna/Rtc
 * 
 */
#include <SoftwareSerial.h>

/* for software wire use below
#include <SoftwareWire.h>  // must be included here so that Arduino library object file references work
#include <RtcDS3231.h>
SoftwareWire myWire(SDA, SCL);
RtcDS3231<SoftwareWire> Rtc(myWire);
 for software wire use above */

/* for normal hardware wire use below */
#include <Wire.h> // must be included here so that Arduino library object file references work
#include <RtcDS3231.h>
RtcDS3231<TwoWire> Rtc(Wire);

// Time to track time between when water pump is tunnered on/off
unsigned long previousIrrigationTime = Rtc.GetDateTime();
>>>>>>> Stashed changes

const String server_VERSION = "v0.2.1";
const String server_RELEASE = "25 October 2020";

// initialize pins
const uint8_t waterSensorLowLedPin  = 2;
const uint8_t waterSensorMidLedPin  = 3;
const uint8_t waterSensorHighLedPin = 4;

const uint8_t waterPumpRelayPin = 5;

const int waterSensorLowPin  = 6;
const int waterSensorMidPin  = 7;
const int waterSensorHighPin = 8;

// used by ESP8266 for serial communication
SoftwareSerial serverSerial(10, 11); // Rx, Tx

const uint8_t ledPin = 12;

const uint8_t waterLevel_empty = 0;
const uint8_t waterLevel_low   = 1;
const uint8_t waterLevel_mid   = 2;
const uint8_t waterLevel_high  = 3;

/**
   setup()
*/
void setup() {

  Serial.begin(9600);
  Serial.println("Sensors: serial connection started...");
  Serial.println("");

  Serial.println("HydroBites Water Station");
  Serial.println(server_VERSION);
  Serial.println(server_RELEASE);
  Serial.println("");

  Serial.println("Sensors: Sensors <-> Server serial connection started...");
  serverSerial.begin(9600);

  Serial.println("Sensors: setup complete...");

  // Assign pins
  // Water sensors
  // pinMode(waterSensorLowPin, INPUT);
  // pinMode(waterSensorMidLedPin, OUTPUT);
  // pinMode(waterSensorHighPin, INPUT);

  // Water pump
  // pinMode(waterPumpRelayPin, OUTPUT);

  // Water sensor level LED indicators
  // pinMode(waterSensorLowLedPin, OUTPUT);
  // pinMode(waterSensorMidPin, INPUT);
  // pinMode(waterSensorHighLedPin, OUTPUT);

  // Test LED
  // pinMode(ledPin, OUTPUT);

  Serial.println("Sensors: pin assignment complete...");

  Serial.println("Sensors: pin assignment complete...");
  Serial.println("");

  // Initialize the rtc (real-time clock) object
  Rtc.Begin();

  RtcDateTime compiled = RtcDateTime(__DATE__, __TIME__);
  printDateTime(compiled);
  Serial.println();

  if (!Rtc.IsDateTimeValid()) {
    Serial.print("WARNING: RTC Invalid Date");
          
    if (Rtc.LastError() != 0) {

      // communications error
      // see https://www.arduino.cc/en/Reference/WireEndTransmission for explination of number values
      Serial.print("RTC communications error = ");
      Serial.println(Rtc.LastError());

    } else {
      
      // Common Causes:
      //   1) first time you ran and the device wasn't running yet
      //   2) the battery on the device is low or even missing
      Serial.println("RTC - lost confidence in the DateTime!");

      // set the RTC to the date and time this sketch was compiled
      // - also resets valid flag internally unless the Rtc device is having an issue
      Rtc.SetDateTime(compiled);
      Serial.println("RTC set to compile time");
    }
  }

  if (!Rtc.GetIsRunning()) {
    Serial.println("RTC was not actively running, starting now");
    Rtc.SetIsRunning(true);
  }


  // RTC setting check
  RtcDateTime now = Rtc.GetDateTime();
  if (now < compiled) {
    Serial.println("RTC is older than compile time!  (Updating DateTime)");
    Rtc.SetDateTime(compiled);
  } else if (now > compiled) {
    Serial.println("RTC is newer than compile time. (this is expected)");
  } else if (now == compiled) {
    Serial.println("RTC is the same as compile time! (not expected but all is good... what are the chances!?!)");
  }

  // Do not assume the Rtc was last configured correctly
  // Clear RTC setting to needed state
  Rtc.Enable32kHzPin(false);
  Rtc.SetSquareWavePin(DS3231SquareWavePin_ModeNone); 

  Serial.println("Real-Time Clock: Initialized...");
  Serial.println();

  /**
     Serial.write are transmitted in the background (from an interrupt handler) allowing your
     sketch code to immediately resume processing. This is usually a good thing (it can make the
     sketch more responsive) but sometimes you want to wait until all characters are sent. You can
     achieve this by calling Serial.flush() immediately following Serial.write().
  */
  Serial.flush();
}

/**
   loop() - event loop
*/
void loop() {
  String serverMessage;
  int irrigationDuration = 0;

  if (!Rtc.IsDateTimeValid()) {
    
    if (Rtc.LastError() != 0) {
      
      // we have a communications error
      // see https://www.arduino.cc/en/Reference/WireEndTransmission for 
      // what the number means
      Serial.print("RTC communications error = ");
      Serial.println(Rtc.LastError());
      
    } else {
      // Common Causes
      //  1) the battery on the device is low or even missing and the power line was disconnected
      Serial.println("RTC lost confidence in the DateTime!");
    }

  }

  RtcDateTime now = Rtc.GetDateTime();
  Serial.print("RTC time: ");
  printDateTime(now);
  Serial.println();

  RtcTemperature temp = Rtc.GetTemperature();
  Serial.print("RTC temperature: ");

  // you may also get the temperature as a float and print it
  // Serial.print(temp.AsFloatDegC());
  temp.Print(Serial);
  Serial.println("C");

  while (serverSerial.available()) {
    serverMessage = serverSerial.readStringUntil('\n');
    Serial.println((String)"Server: " + serverMessage);

    // Router for sensor actions
    if (serverMessage.indexOf("GET /status") >= 0) {

      sendStatus();

    } else if (serverMessage.indexOf("GET /led/toggle") >= 0) {

      int ledState = toggleLed();
      sendLedStatus(ledState);

    } else if (serverMessage.indexOf("GET /led") >= 0) {

      int ledState = getLedStatus();
      sendLedStatus(ledState);

    } else if (serverMessage.indexOf("GET /water/irrigate") >= 0) {

      int waterLevelState = getWaterLevel();
      int waterPumpState = toggleWaterPump(waterLevelState);
      unsigned long irrigationDuration = getPumpToggleDuration();

      sendWaterStatus(waterLevelState, waterPumpState, irrigationDuration);

    } else if (serverMessage.indexOf("GET /water") >= 0) {

      int waterLevelState = getWaterLevel();
      int waterPumpState =  getPumpStatus();
      unsigned long irrigationToggleDuration = getPumpToggleDuration();

      sendWaterStatus(waterLevelState, waterPumpState, irrigationToggleDuration);

    }
  }
}

/**
   Report current serial and sensor status
*/
void sendStatus() {
  int sensorState = 0; // false

  int waterLevelState = getWaterLevel();
  if (waterLevelState > 0) {
    sensorState = 1; // true
  }

  int rtcState = Rtc.GetDateTime();
  if (rtcState > 0) {
    clockState = 1; // true
  }

  // Send Serial message back to server to confirm receipt. If this response works then
  // the serial connection is working
  // serial_status (sr), sensor_status (ss)
  serverSerial.print("sr: 1, ss: ");
  serverSerial.println(sensorState);

  // Log to serial monitor
  Serial.println("serial_status: true, sensor_status: " + sensorState);
}

/**
 * Get the current state of the LED - on(1) / off(0)
 */
int getLedStatus() {
  return digitalRead(ledPin);
}

/**
   Adjust the state of the LED between on/off
*/
int toggleLed() {
  int setLedState = 0;

  // Write the opposite of the current state
  setLedState = !digitalRead(ledPin);
  digitalWrite(ledPin, setLedState);

  Serial.print("led_state: ");
  Serial.println(setLedState);

  return setLedState;
}

/**
   Send Serial message back to server of current led state
*/
void sendLedStatus(int ledState) {
  // Send server led status
  serverSerial.print("ls: ");
  serverSerial.println(ledState);

  // Log led status to local terminal
  Serial.print("led_state: ");
  Serial.println(ledState);
}

/**
   Read water level sensors and toggle related LED
*/
int getWaterLevel() {
  int waterSensorHighStatus = 0;
  int waterSensorMidStatus  = 0;
  int waterSensorLowStatus  = 0;
  bool sensorCheckOk = false;
  int waterLevel = 0;

  // Digital: 1/0
  waterSensorLowStatus  = digitalRead(waterSensorLowPin);
  waterSensorMidStatus  = digitalRead(waterSensorMidPin);
  waterSensorHighStatus = digitalRead(waterSensorHighPin);

  // Set related led to the same on/off state of the water sensor
  digitalWrite(waterSensorLowLedPin, waterSensorLowStatus);
  digitalWrite(waterSensorMidLedPin, waterSensorMidStatus);
  digitalWrite(waterSensorHighLedPin, waterSensorHighStatus);

  // Validate sensor readings, a lower sensor should not have an off status
  // High
  if (waterSensorHighStatus == 1 && waterSensorMidStatus == 1 && waterSensorLowStatus == 1) {
    return 3;
  }

  // Mid
  if (waterSensorHighStatus == 0 && waterSensorMidStatus == 1 && waterSensorLowStatus == 1) {
    return 2;
  }

  // Low
  if (waterSensorHighStatus == 0 && waterSensorMidStatus == 0 && waterSensorLowStatus == 1) {
    return 1;
  }

  // Empty
  if (waterSensorHighStatus == 0 && waterSensorMidStatus == 0 && waterSensorLowStatus == 0) {
    return 0;
  }

  // Error
  return -1;
}

/**
   Adjust the state of water pump between on/off
*/
int toggleWaterPump(int waterLevel) {
  int setPumpState = 0;

  // Error detecting water level
  if (waterLevel == -1) {
    return -1;
  }

  // Do not run pump if water level is low
  if (waterLevel <= waterLevel_mid) {
    return 0;
  }

  // Write the opposite of the current state
  // The relay is active low, it turns on when set to LOW
  setPumpState = !digitalRead(waterPumpRelayPin);

  digitalWrite(waterPumpRelayPin, setPumpState);

  // pump state toggled, set new irrigation time
  previousIrrigationTime = Rtc.GetDateTime();

  Serial.print("water_pump: ");
  Serial.println(setPumpState);

  return setPumpState;
}

/**
   Get the current state of the pump - on (1)/off (0)
*/
int getPumpStatus() {
  return digitalRead(waterPumpRelayPin);
}

/**
   Get the amount of time since the pump was last toggled
*/
unsigned long getPumpToggleDuration() {
  return millis() - previousIrrigationTime;
}

/**
 * Send Serial message back to server of current irrigation (water pump) state
 *
 * wl: x, is: x, id: x
 */
void sendWaterStatus(int waterLevelState, int pumpState, unsigned long irrigationDuration) {
  int seconds = (int) ((irrigationDuration / 1000) % 60);
  int minutes = (int) (((irrigationDuration / 1000) / 60) % 60);
  int hours = (int) ((((irrigationDuration / 1000) / 60) / 24) % 24);
  return Rtc.GetDateTime() - previousIrrigationTime;
  
}

/**
   Send Serial message back to server of current irrigation (water pump) state

   wl: x, ps: x
*/
void sendWaterStatus(int waterLevelState, int pumpState) {

  // Send water level state
  serverSerial.print("wl: ");
  serverSerial.print(waterLevelState);

  // Send pump status
  serverSerial.print(", is: ");
  serverSerial.print(pumpState);

  // Send irrigation duration
  serverSerial.print(", id: ");

  char serverbuf[9];
  sprintf(serverbuf, "%02d:%02d:%02d", hours, minutes, seconds);
  serverSerial.println(serverbuf);

  // Log water level state to local terminal
  Serial.print("water_level: ");
  Serial.println(waterLevelState);

  // Log pump status to local terminal
  Serial.print("irrigation_status: ");
  Serial.println(pumpState);
}

/**
   Send Serial message back to server of irrigation (water pump) running duration since last toggle

   days:hours:minutes:seconds
   id: xxx:xx:xx:xx
*/
void sendIrrigationDuration(unsigned long irrigationDuration) {
  int seconds = (int) ((irrigationDuration / 1000) % 60);
  int minutes = (int) (((irrigationDuration / 1000) / 60) % 60);
  int hours = (int) ((((irrigationDuration / 1000) / 60) / 24) % 24);
  int days = round(((irrigationDuration / 1000) / 60) / 24);

  // Send irrigation duration
  serverSerial.print(", id: ");

  char irrigationDurationBuf[13];
  sprintf(irrigationDurationBuf, "%03d:%02d:%02d:%02d", days, hours, minutes, seconds);
  serverSerial.println(irrigationDurationBuf);

  // Log irrigation duration to local terminal
  Serial.print("irrigation_duration: ");

  char localbuf[9];
  sprintf(localbuf, "%02d:%02d:%02d", hours, minutes, seconds);
  Serial.println(localbuf);
}

#define countof(a) (sizeof(a) / sizeof(a[0]))

void printDateTime(const RtcDateTime& dt) {
  char datestring[20];

  snprintf_P(
    datestring, 
    countof(datestring),
    PSTR("%02u/%02u/%04u %02u:%02u:%02u"),
    dt.Month(),
    dt.Day(),
    dt.Year(),
    dt.Hour(),
    dt.Minute(),
    dt.Second()
  );
  
  Serial.print(datestring);
}

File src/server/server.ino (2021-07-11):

/**
 * HydroBites WaterStation http server
 */

 /**
  * See https://www.deviceplus.com/arduino/arduino-preprocessor-directives-tutorial/
  * for details on how #include works. Specifically the search rules based on "<" and ">"
  * usage for where the preprocessor searches for the file.
  */
#include <ESP8266WiFi.h>
#include <WiFiClient.h>
#include <ESP8266WebServer.h>
#include <ArduinoJson.h>

/**
 * WiFi credentials.
 *
 * Note use of "ifndef" to ensure excisting constant "APSSID" does not attempt to be ressigned.
 * If it's undefined, the next line defines the constant.
 *
 * https://www.arduino.cc/reference/en/language/structure/further-syntax/define/
 *
 * #define is a useful C++ component that allows the programmer to give a name to a constant value
 * before the program is compiled. Defined constants in arduino don’t take up any program memory
 * space on the chip. The compiler will replace references to these constants with the defined value
 * at compile time.
 */
#ifndef APSSID
#define APSSID "HydroBytes_WaterStation"
#define APPSK  "undefined" // password
#endif

/**
 * https://www.arduino.cc/reference/en/language/variables/variable-scope-qualifiers/const/
 *
 * In general, the const keyword is preferred for defining constants and should be used instead
 * of #define.
 */

const char *ssid = APSSID;
const char *password = APPSK;

const String server_VERSION = "v0.3.0";
const String server_RESEASE = "15 May 2021";

const uint8_t response_OK = 200;
const uint8_t response_NOT_FOUND = 404;
const uint8_t response_UNAVAILABLE = 503;

// Instantiate ESP8266WebServer class as "server"
ESP8266WebServer server(80);

/**
 * Setup
 */
void setup() {
  // Wait for serial port to be available
  // Include a delay in the routine. That would allow background tasks that need to run. You can not have long blocking
  // code with the ESP8266. It will cause the behavior:

  // Uno (sensors) - received from ESP-01 (server):
  // 21:40:37.136 ->  ets Jan  8 2013,rst cause:2, boot mode:(3,7)

  // ESP8266 12E keeps rebooting (rst cause:2, boot mode:(3,6))
  // https://github.com/esp8266/Arduino/issues/3241

  // rst cause:2
  // 0 -> normal startup by power on
  // 1 -> hardware watch dog reset
  // 2 -> software watch dog reset (From an exception)
  // 3 -> software watch dog reset system_restart (Possibly unfed watchdog got angry)
  // 4 -> soft restart (Possibly with a restart command)
  // 5 -> wake up from deep-sleep

  // Wait for sensor controller to start as serial monitor is typically connected there for debugging
  // delay() forces the logging to be in the expected order and also ensures timing of serial connection
  // happens in the expected order
  delay(10000);

  // Connect to local serial port. Used to send messages to sensor controller
  Serial.begin(9600);

  Serial.println("HydroBites Water Station - Server");
  Serial.println(server_VERSION);
  Serial.println(server_RESEASE);
  Serial.println("");

  Serial.println("Configuring access point...");

  /* Password parameter removed to make open network.
   * WiFi.softAP(ssid, password);
   */
  Serial.print("Setting soft-AP ... ");
  WiFi.softAP(ssid) ? "Ready" : "Failed!";
  Serial.println("");

  IPAddress stationIP = WiFi.softAPIP();
  Serial.print("AP (station) IP address: ");
  Serial.println(stationIP);

  Serial.print("Local IP address: ");
  Serial.println(WiFi.localIP());
  Serial.flush();

  // server routers
  server.on("/", HTTP_GET, handleRoot);
  server.on("/status", HTTP_GET, requestStatus);
  server.on("/led", HTTP_GET, requestLedStatus);
  server.on("/led/toggle", HTTP_GET, requestLedToggle);
  server.on("/water", HTTP_GET, requestWaterLevel);
  server.on("/water/irrigate", HTTP_GET, requestIrrigateToggle);

  server.begin();
  Serial.println("HTTP server started");
  Serial.flush();
}

/**
 * Event loop
 */
void loop() {
  String sensorMessage;

  // Serial messages from sensors (Uno)
  while (Serial.available()) {
    sensorMessage = Serial.readStringUntil('\n');

    // serial_status
    if (sensorMessage.indexOf("ss:") >= 0) {
      responseStatus(sensorMessage);

    // led_status
    } else if (sensorMessage.indexOf("ls:") >= 0) {
      responseLedStatus(sensorMessage);

    // water_status (wl: x, ps: x, id: xx:xx:xx)
    } else if (sensorMessage.indexOf("id:") >= 0) {
      responseWaterLevel(sensorMessage);

    // irrigation_status (wl: x, ps: x)
    } else if (sensorMessage.indexOf("wl:") >= 0) {
      responseIrrigate(sensorMessage);
    }
  }

  // Process http requests
  server.handleClient();
}

/*
 * Controllers
 * 
 * handleRoot
 * Go to http://192.168.4.1 in web browser for http access to network
 */
void handleRoot() {
  String buf;
  DynamicJsonDocument doc(512);

  // Write to serial channel to inform Ardunio (Uno) of event
  Serial.println("GET /");

  // Compose response
  doc["hydrobytes-water-station"] = "ok";

  doc["release"]["version"] = server_VERSION;
  doc["release"]["date"] = server_RESEASE;

  doc["paths"]["/"] = "Welcome";
  doc["paths"]["/status"] = "Current health of subsystems";
  doc["paths"]["/led"] = "Current state of LED - on/off";
  doc["paths"]["/led/toggle"] = "Toggle LED on/off";
  doc["paths"]["/water"] = "Current water status";
  doc["paths"]["/water/irrigate"] = "Toggle irrigation on/off";

  serializeJson(doc, buf);

  server.send(response_OK, F("application/json"), buf);
}

/**
 * Status request controller
 */
void requestStatus() {
  Serial.println("GET /status");
}

/**
 * Status request response. Returns http response to server http request based on
 * status reponse from sensor controller.
 *
 * Go to http://192.168.4.1/status
 */
void responseStatus(String sensorMessage) {
  String serialStatus;
  String sensorStatus;
  String clockStatus;
  String buf;
  DynamicJsonDocument doc(256);
  uint8_t responseCode = response_OK;

  // sr: x, ss: x, cs: x
  // serial_status: x, sensor_status: x, clock_status: x
  serialStatus = sensorMessage.substring(4, 5);
  serialStatus.trim();
  serialStatus = serialStatus == "1" ? "true" : "false";

  sensorStatus = sensorMessage.substring(11, 12);
  sensorStatus.trim();
  sensorStatus = sensorStatus == "1" ? "true" : "false";

    // Serial.println("responseStatus() sensorStatus preTrim(): ->" + sensorStatus + "<-");

  clockStatus = sensorMessage.substring(17, 18);
  clockStatus.trim();
  clockStatus = clockStatus == "1" ? "true" : "false";

  // Compose response
  if (serialStatus != "true" || sensorStatus != "true" || clockStatus != "true") {
    responseCode = response_UNAVAILABLE;
  }

  doc["status"]["two-way-serial-communication"] = serialStatus;
  doc["status"]["water-sensors"] = sensorStatus;
  doc["status"]["real-time-clock"] = clockStatus;
  serializeJson(doc, buf);

  server.send(responseCode, F("application/json"), buf);
}

/**
 * LED status serial request to sensor micro controller
 */
void requestLedStatus() {
  Serial.println("GET /led");
}
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

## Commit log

2020-07-25 Initial working solution of server (esp2222222266-esp-01) and sensor controller (Adrunio uno) communicating serially
2020-07-26 Expand on v0.0.1 notes to include images and links to USB adapter and voltage regulator
2020-08-14 Issue-4 Add PONG logic to sensor controller
    [sensors.ino]
2020-08-14 Issue-4 Add PING logic to server controller
    [server.ino]
2020-08-15 Issue-4 Added serial listening logic to loop() to support messages from server events
    [sensors.ino]
2020-08-15 Issue-4 adds details to GET / and GET /status responses
    [server.ino]
2020-08-15 Issue-4 create schematic diagram and related release notes
    [sketch-v0-0-1.fzz]
2020-08-16 Issue-1 documentation and release notes
    [sketch-v0-0-1.fzz]
2020-08-16 Issue-1 proof reading and typos
    [server.ino]
2020-08-17 Issue-3 Add logic for water level sensors
    [sensors.ino]
2020-08-17 Issue-3 refactor to use switch/case
    [sensors.ino]
2020-08-31 Issue-3 addition of leds to also indicate the current water level reading on the beadboard
    [sensors.ino]
2020-08-31 Issue-3 addition of GET /water endpoint
    [server.ino]
2020-08-31 documentation update
    [sketch-v0-1-x.fzz]
2020-09-20 refactor to support sensor status request and move to constants for status code responses
2020-09-20 Adds liquid sensor reference
2020-09-27 Addition of YouTube channel as well as general release notes clean up to include images and videos to help document the project. Document define vs const usage.
    [sketch-v0-1-x.fzz]
2020-10-18 Issue-10 documentation update with details about release for water pump support
    [sensors.ino]
2020-10-18 Issue-10 move to ArduinoJson library
    [server.ino]
2020-10-18 Issue-10 add support for /water/irrigation
    [sensors.ino]
2020-10-19 Issue-10 additional notes on relay and the ArduinoJson library
2020-10-19 Issue-10 bug fix, irrigation_status reversed
    [sensors.ino]
2020-10-19 Issue-10 adjustment of DynamicJsonDocument size to match response payload size - better use of memory
    [server.ino]
2020-10-20 Issue-10 breadboard and schematic references
    [sketch-v0-2-x.fzz]
2020-10-22 v0.2.1 refactor to use short form serial messages from sensor to server controllers
    [sensors.ino, server.ino]
2020-10-25 v0.2.1 bug fixes - responseCode type, serial message length
    [sensors.ino, server.ino]
2020-10-25 v0.2.1 add logic to deal with invalid sensor readings
2020-10-25 v0.2.1 response bug fix and sensor return value error checking logic
    [server.ino]
